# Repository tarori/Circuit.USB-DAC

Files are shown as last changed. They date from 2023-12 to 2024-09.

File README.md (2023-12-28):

USB Audio DAC version 10
 * Input: USB Audio class 2.0 (192kHz/24bit)
 * Output: Headphone and speakers (max 5W @8Ω)
 * THD+N < -100dB (0.001%) at 1W 8Ω 
 * Low output noise: <10uVrms (20-20kHz)
 * 4-layer PCB with solid ground
 * SDR-Widget with very low jitter design
 * Isolated USB input
 * AK4493 with AK1110 and [LED regulators](https://github.com/tarori/Circuit.LEC-Regulator) (discrete low noise, low impedance regulator) 
 * Low gain class-AB amplifier
 * Two mute relays for headphone and speakers
 * Input power: ±20V 2A

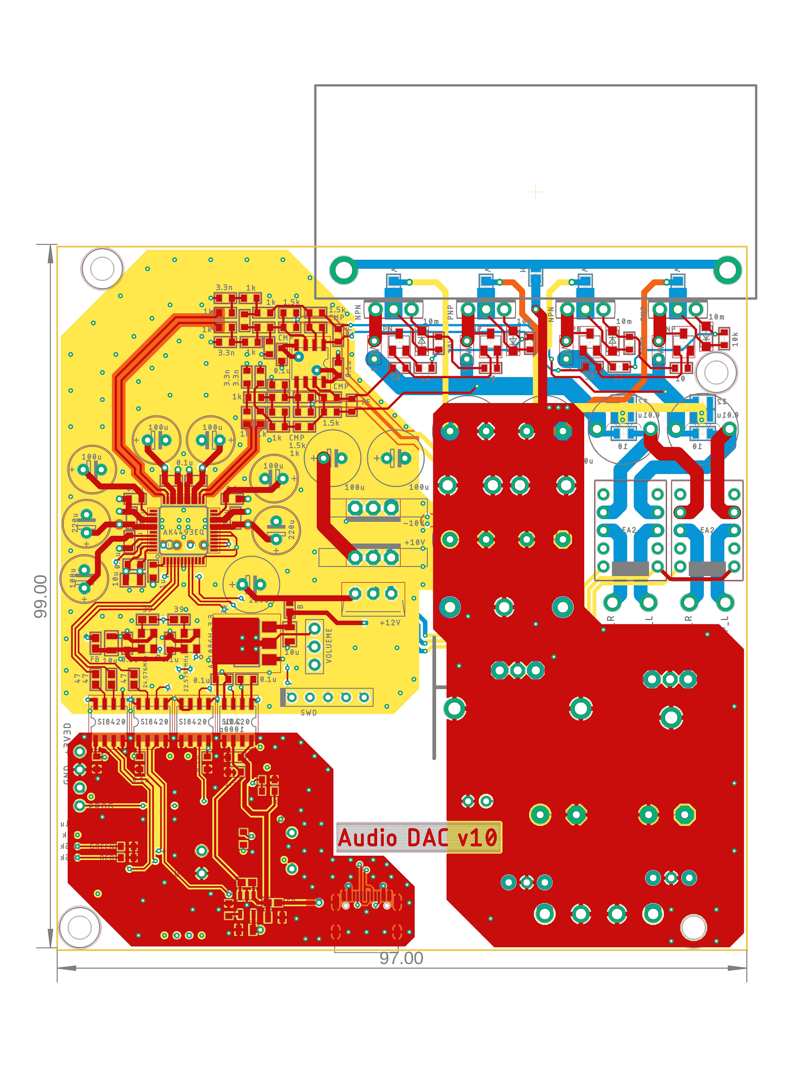
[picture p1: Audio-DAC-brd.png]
ボード図

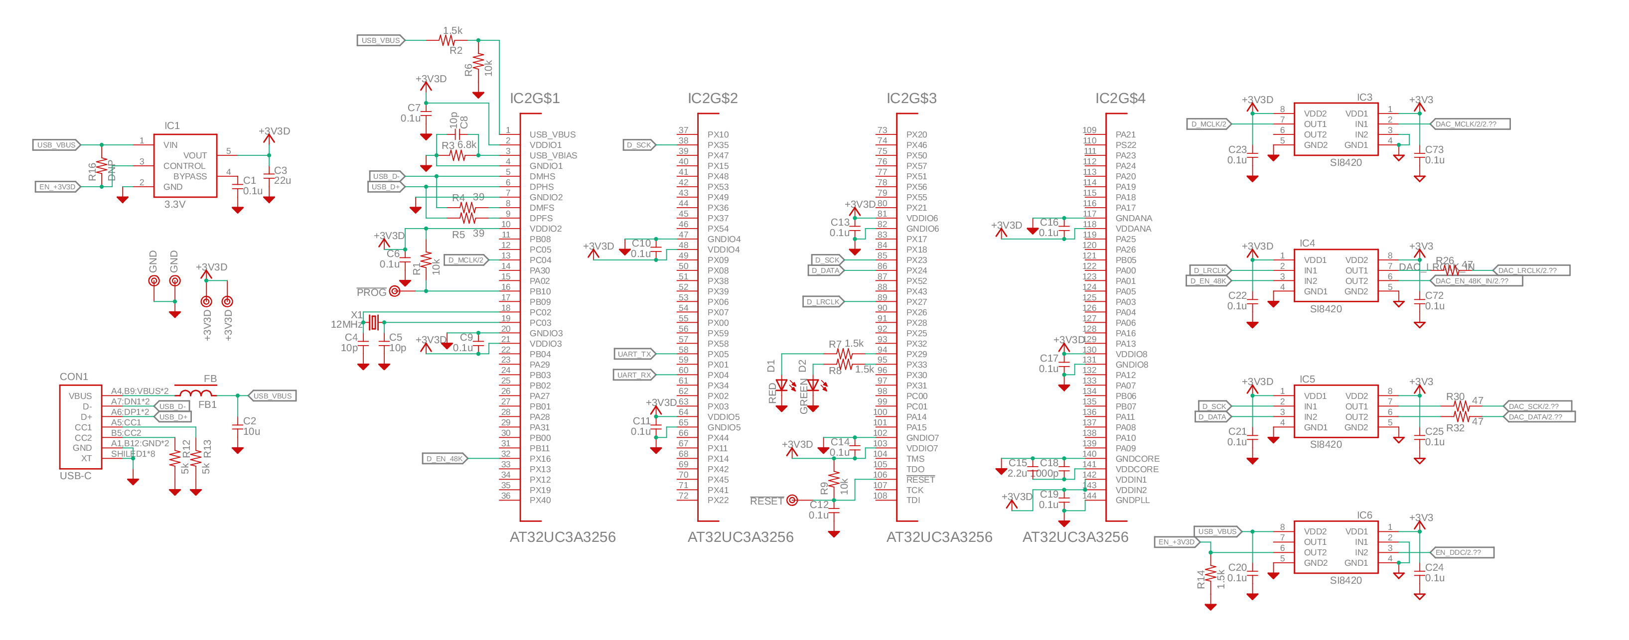
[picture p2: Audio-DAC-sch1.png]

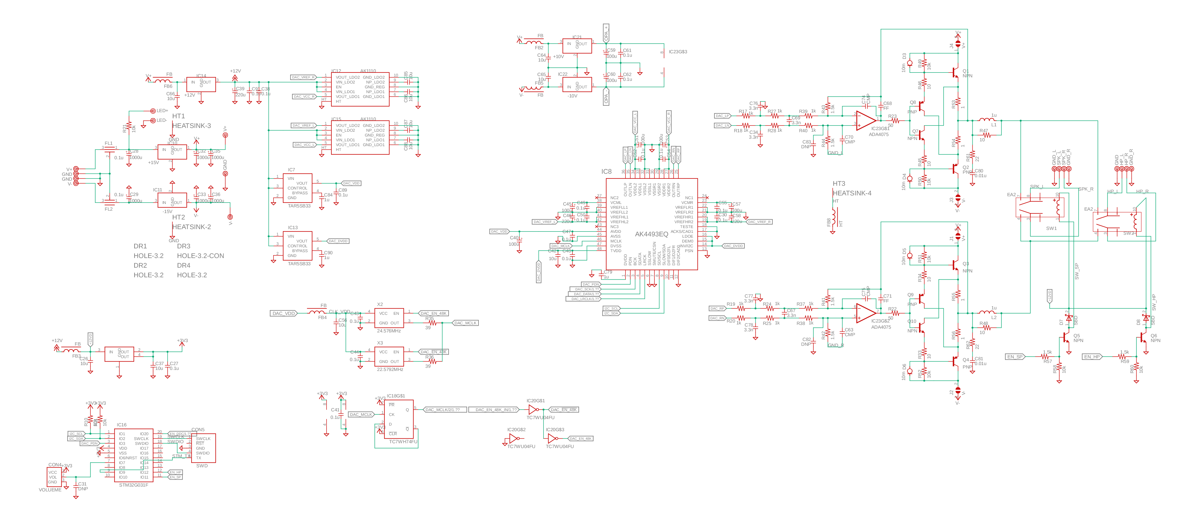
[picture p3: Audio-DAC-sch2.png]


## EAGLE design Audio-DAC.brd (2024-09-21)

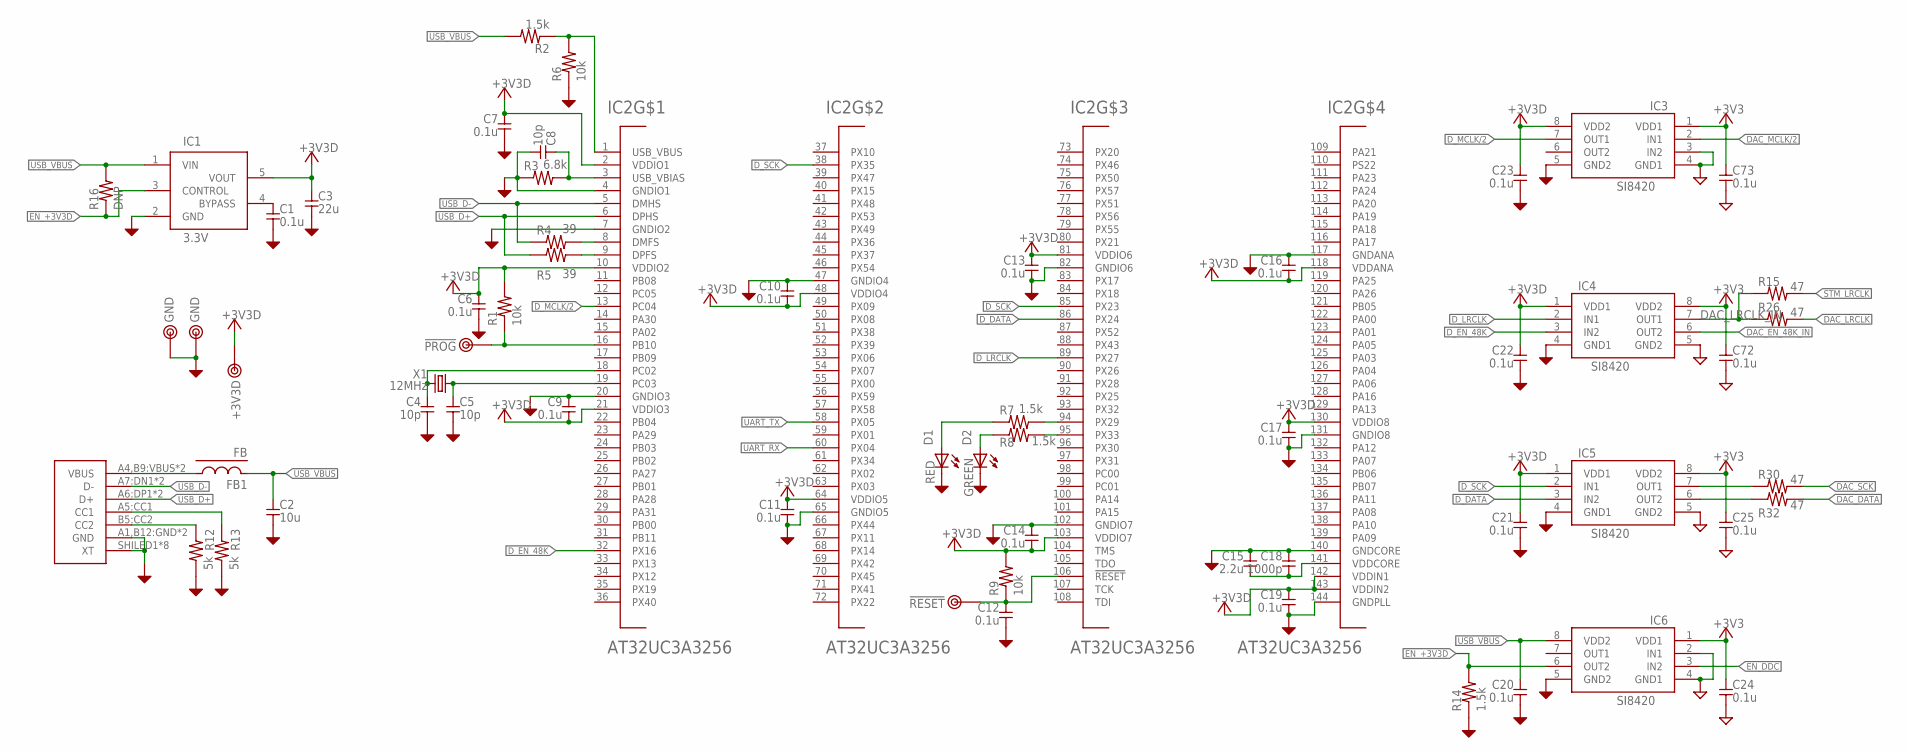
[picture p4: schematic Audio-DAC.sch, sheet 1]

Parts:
C1, C6, C7, C9, C10, C11, C12, C13, C14, C16, C17, C19, C20, C21, C22, C23, C24, C25, C72, C73: 0.1u; 1608C
C2: 10u; 2012
C3: 22u; 2012
C4, C5, C8: 10p; 1608C
C15: 2.2u; 2012
C18: 1000p; 1608C
CON1: USB-C; 5077CR-16-SMC2-BK-TR
D1: RED; D1608
D2: GREEN; D1608
FB1: FB; 1608-J
IC1: 3.3V; SOT23-5
IC2: AT32UC3A3256; TQFP144
IC3, IC4, IC5, IC6: SI8420; SOP8
R1, R6, R9: 10k; 1608
R2, R7, R8, R14: 1.5k; 1608
R3: 6.8k; 1608
R4, R5: 39; 1608
R12, R13: 5k; 1608
R15, R26, R30, R32: 47; 1608-J
R16: DNP; 1608-J
TP1: !PROG; TESTPIN
TP2: !RESET; TESTPIN
TP3, TP25: GND; TESTPIN
TP26: +3V3D; TESTPIN
X1: 12MHz; HC49/S

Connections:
+3V3: C24.1, C25.1, C72.1, C73.1, IC3.1 (VDD1), IC4.8 (VDD2), IC5.8 (VDD2), IC6.1 (VDD1); also elsewhere on the board
+3V3D: C3.1, C6.1, C7.1, C9.2, C10.2, C11.1, C13.1, C14.2, C16.2, C17.1, C19.1, C21.1, C22.1, C23.1, IC1.5 (VOUT), IC2.2 (VDDIO1), IC2.10 (VDDIO2), IC2.21 (VDDIO3), IC2.48 (VDDIO4), IC2.64 (VDDIO5), IC2.81 (VDDIO6), IC2.103 (VDDIO7), IC2.118 (VDDANA), IC2.130 (VDDIO8), IC2.142 (VDDIN1), IC2.143 (VDDIN2), IC3.8 (VDD2), IC4.1 (VDD1), IC5.1 (VDD1), R1.2, R9.2, TP26.1
AVR_PROG: IC2.16 (PB10), R1.1, TP1.1
DAC_DATA: R32.2; also elsewhere on the board
DAC_EN_48K_IN: IC4.6 (OUT2); also elsewhere on the board
DAC_LRCLK: R26.2; also elsewhere on the board
DAC_LRCLK_IN: IC4.7 (OUT1), R15.1, R26.1
DAC_MCLK/2: IC3.2 (IN1); also elsewhere on the board
DAC_SCK: R30.2; also elsewhere on the board
DGND: C1.2, C2.2, C3.2, C4.2, C5.2, C6.2, C7.2, C8.2, C9.1, C10.1, C11.2, C12.2, C13.2, C14.1, C15.1, C16.1, C17.2, C18.1, C19.2, C20.2, C21.2, C22.2, C23.2, CON1.A1,B12:GND (GND), CON1.B1,A12:GND (GND), CON1.SHILED1 (XT), CON1.SHILED2 (XT), CON1.SHILED3 (XT), CON1.SHILED4 (XT), CON1.SHILED5 (XT), CON1.SHILED6 (XT), CON1.SHILED7 (XT), CON1.SHILED8 (XT), D1.K, D2.K, IC1.2 (GND), IC2.4 (GNDIO1), IC2.7 (GNDIO2), IC2.20 (GNDIO3), IC2.47 (GNDIO4), IC2.65 (GNDIO5), IC2.82 (GNDIO6), IC2.102 (GNDIO7), IC2.117 (GNDANA), IC2.131 (GNDIO8), IC2.140 (GNDCORE), IC2.144 (GNDPLL), IC3.5 (GND2), IC4.4 (GND1), IC5.4 (GND1), IC6.5 (GND2), R3.1, R6.1, R12.1, R13.1, R14.1, TP3.1, TP25.1
D_!RST: C12.1, IC2.106 (!RESET), R9.1, TP2.1
D_DATA: IC2.86 (PX24), IC5.3 (IN2)
D_EN_48K: IC2.32 (PX16), IC4.3 (IN2)
D_LRCLK: IC2.89 (PX27), IC4.2 (IN1)
D_MCLK/2: IC2.13 (PC04), IC3.7 (OUT1)
D_SCK: IC2.38 (PX35), IC2.85 (PX23), IC5.2 (IN1)
EN_+3V3D: IC1.3 (CONTROL), IC6.6 (OUT2), R14.2, R16.1
EN_DDC: IC6.3 (IN2); also elsewhere on the board
GND: C24.2, C25.2, C72.2, C73.2, IC3.3 (IN2), IC3.4 (GND1), IC4.5 (GND2), IC5.5 (GND2), IC6.2 (IN1), IC6.4 (GND1); also elsewhere on the board
LED_GREEN: IC2.95 (PX33), R8.2
LED_RED: IC2.94 (PX29), R7.2
unnamed: IC2.8 (DMFS), R4.2
unnamed: IC2.9 (DPFS), R5.2
unnamed: C5.1, IC2.19 (PC03), X1.1
unnamed: C4.1, IC2.18 (PC02), X1.2
unnamed: C8.1, IC2.3 (USB_VBIAS), R3.2
unnamed: IC2.1 (USB_VBUS), R2.1, R6.2
unnamed: D2.A, R8.1
unnamed: C15.2, C18.2, IC2.141 (VDDCORE)
unnamed: D1.A, R7.1
unnamed: IC5.7 (OUT1), R30.1
unnamed: C1.1, IC1.4 (BYPASS)
unnamed: CON1.B5:CC2 (CC2), R12.2
unnamed: CON1.A5:CC1 (CC1), R13.2
unnamed: IC5.6 (OUT2), R32.1
STM_LRCLK: R15.2; also elsewhere on the board
UART_RX: IC2.60 (PX04)
UART_TX: IC2.58 (PX05)
USB_D+: CON1.A6:DP1 (D+), CON1.B6:DP2 (D+), IC2.6 (DPHS), R5.1
USB_D-: CON1.A7:DN1 (D-), CON1.B7:DN2 (D-), IC2.5 (DMHS), R4.1
USB_VBUS: C2.1, C20.1, FB1.2, IC1.1 (VIN), IC6.8 (VDD2), R2.2, R16.2
VBUS: CON1.A4,B9:VBUS (VBUS), CON1.B4,A9:VBUS (VBUS), FB1.1

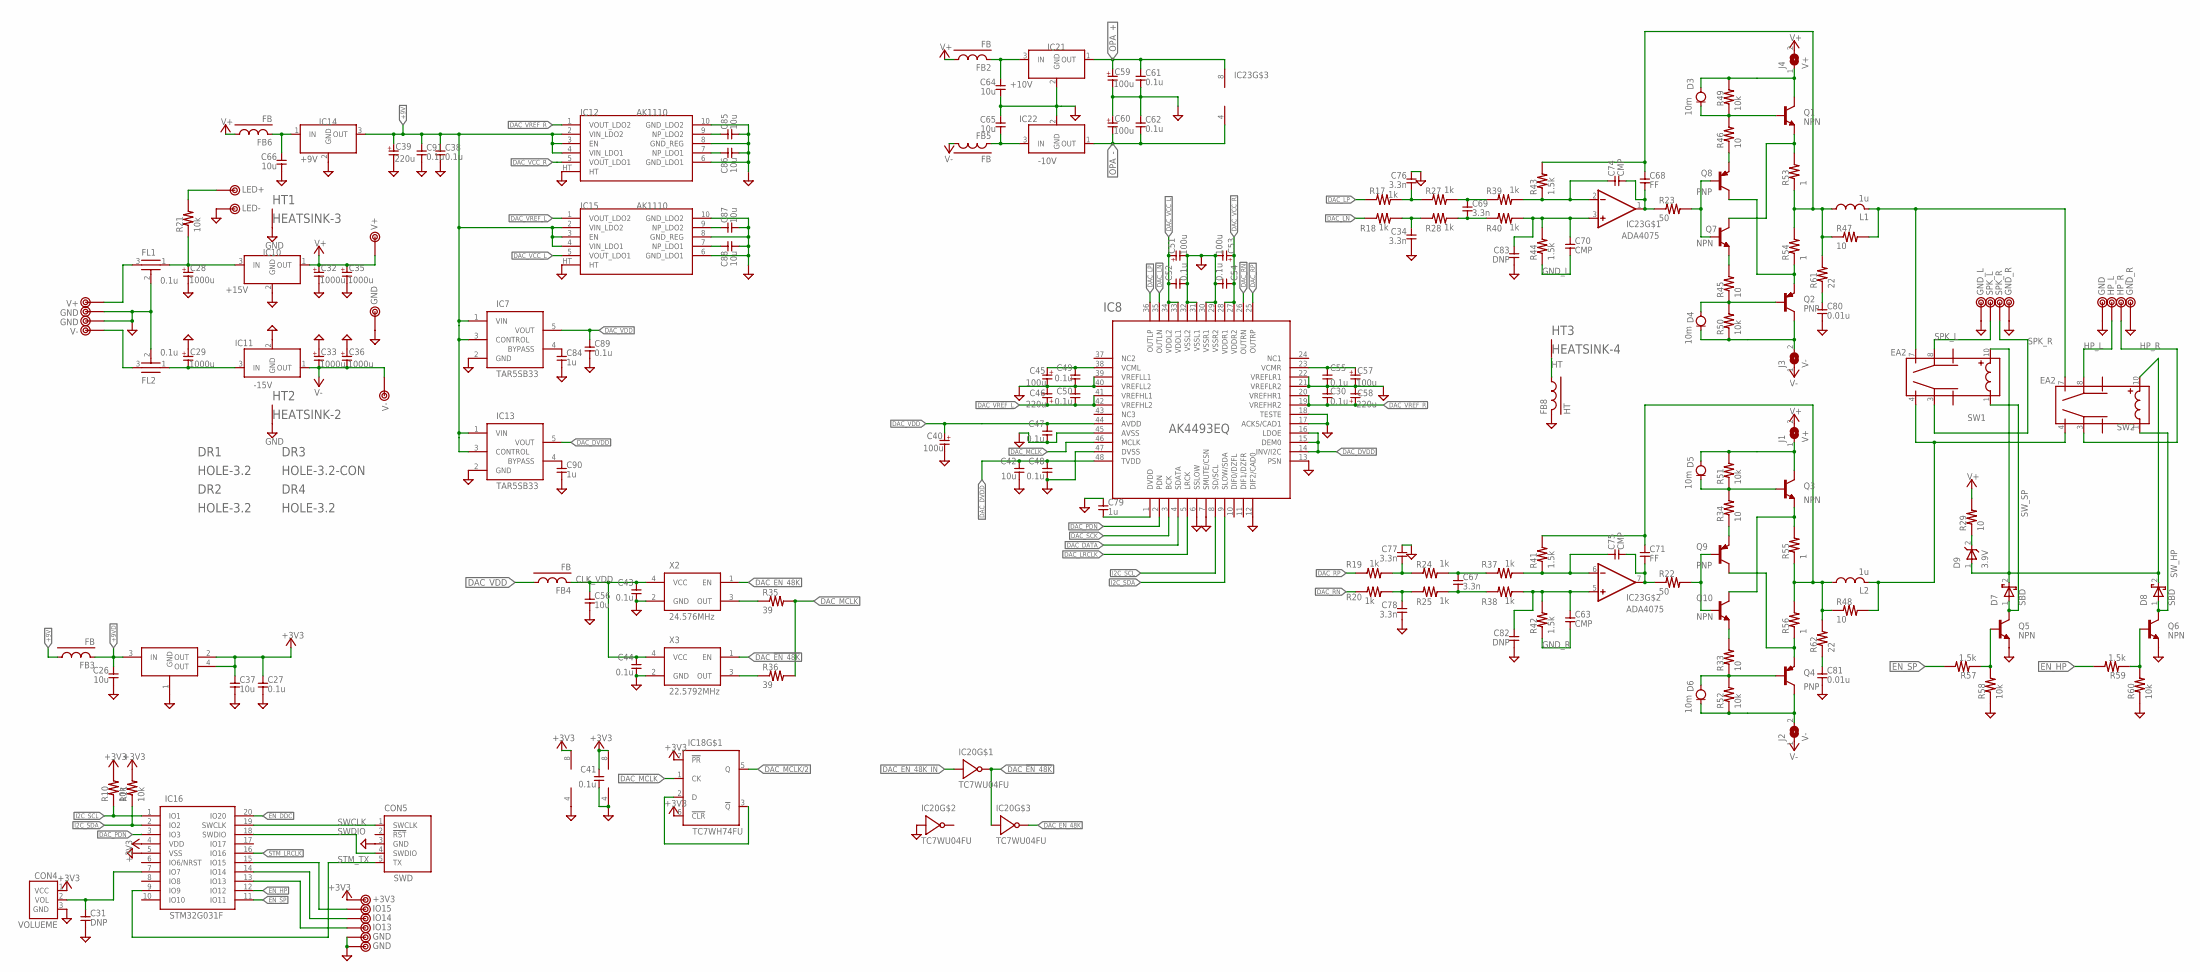
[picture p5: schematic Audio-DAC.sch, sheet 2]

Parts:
C26, C37, C42, C56, C64, C65, C66, C85, C86, C87, C88: 10u; 2012
C27, C30, C38, C41, C43, C44, C47, C48, C49, C50, C52, C54, C55, C61, C62, C89, C91: 0.1u; 1608C
C28, C29: 1000u; E5-13
C31, C82, C83: DNP; 1608C
C32, C33, C35, C36: 1000u; E5-10
C34, C67, C69, C76, C77, C78: 3.3n; 1608C
C39: 220u; E2,5-8
C40, C45, C51, C53, C57: 100u; E2.5-6.5
C46, C58: 220u; E2.5-6.5
C59, C60: 100u; E2,5-8
C63, C70, C74, C75: CMP; 1608C
C68, C71: FF; 1608C
C79, C84, C90: 1u; 1608C
C80, C81: 0.01u; 2012
CON4: VOLUEME; VOL_CON
CON5: SWD; SWD_CON
D3, D4, D5, D6: 10m; SOD123
D7, D8: SBD; SOD123
D9: 3.9V; SOD123
DR1, DR2, DR4: HOLE-3.2; HOLE_3.2
DR3: HOLE-3.2-CON; HOLE_3.2_CON
FB2, FB3, FB4, FB5, FB6: FB; 1608-J
FB8: HT; 2012-J
FL1, FL2: 0.1u; FL1
HT1: HEATSINK-3; HEATSINK3
HT2: HEATSINK-2; HEATSINK2
HT3: HEATSINK-4; HEATSINK4
IC7, IC13: TAR5SB33; SOT23-5
IC8: AK4493EQ; LQFP48
IC9: AZ1086H-3.3; SOT223
IC10: +15V; REGULATOR_LED
IC11: -15V; REGULATOR_LED
IC12, IC15: AK1110; PLP10-SMD
IC14: +9V; TO-220
IC16: STM32G031F; TSSOP20
IC18: TC7WH74FU; SSOP8-P-0.65
IC20: TC7WU04FU; SSOP8-P-0.65
IC21: +10V; REGULATOR_LED
IC22: -10V; REGULATOR_LED
IC23: ADA4075; SOP8
J1, J4: V+; 2012-J
J2, J3: V-; 2012-J
L1, L2: 1u; L7-10-2
Q1, Q3: NPN; TO126
Q2, Q4: PNP; TO126
Q5, Q6, Q7, Q10: NPN; SC59
Q8, Q9: PNP; SC59
R10, R11, R49, R50, R51, R52, R58, R60: 10k; 1608
R17, R18, R19, R20, R24, R25, R27, R28, R37, R38, R39, R40: 1k; 1608
R21: 10k; 2012
R22, R23: 50; 1608
R29, R47, R48: 10; 2012
R33, R34, R45, R46: 10; 1608
R35, R36: 39; 1608-J
R41, R42, R43, R44, R57, R59: 1.5k; 1608
R53, R55, R56: 1; 0207/2V
R54: 1; 0204/5
R61, R62: 22; 2012
SW1, SW2: EA2
TP5, TP11: V+; TESTPIN-BIG
TP6, TP7, TP22, TP31: GND; TESTPIN-BIG
TP8, TP21: V-; TESTPIN-BIG
TP9: IO15; TESTPIN
TP10: IO14; TESTPIN
TP12: IO13; TESTPIN
TP13, TP14: GND; TESTPIN
TP15: LED+; TESTPIN
TP16: LED-; TESTPIN
TP17: +3V3; TESTPIN
TP27: GND_L; TESTPIN-BIG
TP28: SPK_L; TESTPIN-BIG
TP29: SPK_R; TESTPIN-BIG
TP30, TP34: GND_R; TESTPIN-BIG
TP32: HP_L; TESTPIN-BIG
TP33: HP_R; TESTPIN-BIG
X2: 24.576MHz; KC3225
X3: 22.5792MHz; KC3225

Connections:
+3V3: C27.1, C37.1, C41.1, CON4.1 (VCC), IC9.2 (OUT), IC9.4 (OUT), IC16.4 (VDD), IC18.6 (!CLR), IC18.7 (!PR), IC18.8 (V+), IC20.8 (V+), R10.2, R11.2, TP17.1; also elsewhere on the board
+9V: C38.1, C39.+ (1), C91.1, FB3.1, IC7.1 (VIN), IC7.3 (CONTROL), IC12.2 (VIN_LDO2), IC12.3 (EN), IC12.4 (VIN_LDO1), IC13.1 (VIN), IC13.3 (CONTROL), IC14.3 (OUT), IC15.2 (VIN_LDO2), IC15.3 (EN), IC15.4 (VIN_LDO1)
+9VD: C26.1, FB3.2, IC9.3 (IN)
+12V: D7.2 (K), D8.2 (K), D9.1 (A), SW1.10 (L2), SW2.10 (L2)
AMP_LOUT: C68.1, L1.1, R43.2, R47.1, R53.1, R54.2, R61.2
AMP_ROUT: C71.1, L2.1, R41.2, R48.1, R55.1, R56.2, R62.2
CLK_VDD: C43.1, C44.1, C56.1, FB4.2, X2.4 (VCC), X3.4 (VCC)
DAC_!EN_48K: IC20.3 (IN), IC20.7 (OUT), X3.1 (EN)
DAC_DATA: IC8.4 (SDATA); also elsewhere on the board
DAC_DVDD: C42.1, C48.1, IC8.14 (INV/I2C), IC8.15 (DEM0), IC8.16 (LDOE), IC8.48 (TVDD), IC13.5 (VOUT)
DAC_EN_48K: IC20.5 (OUT), X2.1 (EN)
DAC_EN_48K_IN: IC20.1 (IN); also elsewhere on the board
DAC_LN: IC8.35 (OUTLN), R18.1
DAC_LP: IC8.36 (OUTLP), R17.1
DAC_LRCLK: IC8.5 (LRCK); also elsewhere on the board
DAC_MCLK: IC8.46 (MCLK), IC18.1 (CK), R35.2, R36.2
DAC_MCLK/2: IC18.5 (Q); also elsewhere on the board
DAC_PDN: IC8.2 (PDN), IC16.3 (IO3)
DAC_RN: IC8.26 (OUTRN), R20.1
DAC_RP: IC8.25 (OUTRP), R19.1
DAC_SCK: IC8.3 (BCK); also elsewhere on the board
DAC_VCC_L: C51.+ (1), C52.1, IC8.33 (VDDL1), IC8.34 (VDDL2), IC15.5 (VOUT_LDO1)
DAC_VCC_R: C53.+ (1), C54.1, IC8.27 (VDDR2), IC8.28 (VDDR1), IC12.5 (VOUT_LDO1)
DAC_VDD: C40.+ (1), C47.1, C89.1, FB4.1, IC7.5 (VOUT), IC8.44 (AVDD)
DAC_VREF_L: C46.+ (1), C50.2, IC8.41 (VREFHL1), IC8.42 (VREFHL2), IC15.1 (VOUT_LDO2)
DAC_VREF_R: C30.2, C58.+ (1), IC8.19 (VREFHR2), IC8.20 (VREFHR1), IC12.1 (VOUT_LDO2)
EN_DDC: IC16.20 (IO20); also elsewhere on the board
EN_HP: IC16.12 (IO12), R59.2
EN_SP: IC16.11 (IO11), R57.2
GND: C26.2, C27.2, C28.- (2), C29.+ (1), C30.1, C31.2, C32.- (2), C33.+ (1), C34.2, C35.- (2), C36.+ (1), C37.2, C38.2, C39.- (2), C40.- (2), C41.2, C42.2, C43.2, C44.2, C45.- (2), C46.- (2), C47.2, C48.2, C49.2, C50.1, C51.- (2), C52.2, C53.- (2), C54.2, C55.2, C56.2, C57.- (2), C58.- (2), C59.- (2), C60.+ (1), C61.2, C62.1, C64.2, C65.1, C66.2, C76.1, C77.1, C78.2, C79.1, C80.2, C81.2, C82.2, C83.2, C84.2, C85.2, C86.2, C87.2, C88.2, C89.2, C90.2, C91.2, CON4.3 (GND), CON5.3 (GND), FB8.2, FL1.2 (GND), FL2.2 (GND), HT1.HT1, HT1.HT2, HT2.HT1, IC7.2 (GND), IC8.6 (SSLOW), IC8.7 (SMUTE/CSN), IC8.12 (DIF2/CAD0), IC8.13 (PSN), IC8.17 (ACKS/CAD1), IC8.18 (TESTE), IC8.21 (VREFLR2), IC8.22 (VREFLR1), IC8.29 (VSSR2), IC8.30 (VSSR1), IC8.31 (VSSL1), IC8.32 (VSSL2), IC8.39 (VREFLL1), IC8.40 (VREFLL2), IC8.45 (AVSS), IC8.47 (DVSS), IC9.1 (GND), IC10.2 (GND), IC11.2 (GND), IC12.6 (GND_LDO1), IC12.8 (GND_REG), IC12.10 (GND_LDO2), IC12.HT, IC13.2 (GND), IC14.2 (GND), IC15.6 (GND_LDO1), IC15.8 (GND_REG), IC15.10 (GND_LDO2), IC15.HT, IC16.5 (VSS), IC18.4 (V-), IC20.4 (V-), IC20.6 (IN), IC21.2 (GND), IC22.2 (GND), Q5.2 (E), Q6.2 (E), R58.1, R60.1, TP6.1, TP7.1, TP13.1, TP14.1, TP16.1, TP22.1, TP27.1, TP30.1, TP31.1, TP34.1, X2.2 (GND), X3.2 (GND); also elsewhere on the board
GND_L: C70.2, R44.1
GND_R: C63.2, R42.1
HP_L: SW2.8 (COM2), TP32.1
HP_R: SW2.3 (COM1), TP33.1
HT: FB8.1, HT3.HT1, HT3.HT2
I2C_SCL: IC8.8 (SD/SCL), IC16.1 (IO1), R10.1
I2C_SDA: IC8.9 (SLOW/SDA), IC16.2 (IO2), R11.1
unnamed: C84.1, IC7.4 (BYPASS)
unnamed: C86.1, IC12.7 (NP_LDO1)
unnamed: C85.1, IC12.9 (NP_LDO2)
unnamed: C87.1, IC15.9 (NP_LDO2)
unnamed: D4.1 (A), Q2.3 (B), R45.1, R50.2
unnamed: C90.1, IC13.4 (BYPASS)
unnamed: C64.1, FB2.2, IC21.3 (IN)
unnamed: C75.1, IC23.6 (-IN), R37.2, R41.1
unnamed: C63.1, C82.1, IC23.5 (+IN), R38.2, R42.2
unnamed: C65.2, FB5.2, IC22.3 (IN)
unnamed: C66.1, FB6.2, IC14.1 (IN)
unnamed: Q3.1 (E), Q10.3 (C), R55.2
unnamed: Q9.1 (B), Q10.1 (B), R22.2
unnamed: C69.1, R27.2, R39.1
unnamed: Q4.1 (E), Q9.3 (C), R56.1
unnamed: Q9.2 (E), R34.1
unnamed: Q2.1 (E), Q8.3 (C), R54.1
unnamed: Q1.1 (E), Q7.3 (C), R53.2
unnamed: L2.2, R48.2, SW1.4 (A1), SW2.4 (A1)
unnamed: L1.2, R47.2, SW1.7 (A2), SW2.7 (A2)
unnamed: Q5.1 (B), R57.1, R58.2
unnamed: IC16.13 (IO13), TP12.1
unnamed: C69.2, R28.2, R40.1
unnamed: IC16.14 (IO14), TP10.1
unnamed: FL1.3 (IN), TP5.1
unnamed: FL2.3 (IN), TP8.1
unnamed: C77.2, R19.2, R24.1
unnamed: C78.1, R20.2, R25.1
unnamed: R21.2, TP15.1
unnamed: C74.1, IC23.2 (-IN), R39.2, R43.1
unnamed: C70.1, C83.1, IC23.3 (+IN), R40.2, R44.2
unnamed: C79.2, IC8.1 (DVDD)
unnamed: C71.2, C75.2, IC23.7 (OUT), R22.1
unnamed: Q6.1 (B), R59.1, R60.2
unnamed: D3.2 (K), Q1.3 (B), R46.2, R49.1
unnamed: C68.2, C74.2, IC23.1 (OUT), R23.1
unnamed: Q10.2 (E), R33.2
unnamed: IC16.15 (IO15), TP9.1
unnamed: Q7.1 (B), Q8.1 (B), R23.2
unnamed: D6.1 (A), Q4.3 (B), R33.1, R52.2
unnamed: D6.2 (K), J2.2, Q4.2 (C), R52.1
unnamed: D5.2 (K), Q3.3 (B), R34.2, R51.1
unnamed: Q7.2 (E), R45.2
unnamed: Q8.2 (E), R46.1
unnamed: C67.1, R24.2, R37.1
unnamed: D5.1 (A), J1.1, Q3.2 (C), R51.2
unnamed: D4.2 (K), J3.2, Q2.2 (C), R50.1
unnamed: D3.1 (A), J4.1, Q1.2 (C), R49.2
unnamed: C67.2, R25.2, R38.1
unnamed: C76.2, R17.2, R27.1
unnamed: C34.1, R18.2, R28.1
unnamed: C80.1, R61.1
unnamed: C81.1, R62.1
unnamed: C88.1, IC15.7 (NP_LDO1)
unnamed: D9.2 (C), R29.1
unnamed: C31.1, CON4.2 (VOL), IC16.7 (IO7)
unnamed: R35.1, X2.3 (OUT)
unnamed: R36.1, X3.3 (OUT)
unnamed: IC18.2 (D), IC18.3 (!Q)
OPA_+: C59.+ (1), C61.1, IC21.1 (OUT), IC23.8 (V+)
OPA_-: C60.- (2), C62.2, IC22.1 (OUT), IC23.4 (V-)
SPK_L: SW1.8 (COM2), TP28.1
SPK_R: SW1.3 (COM1), TP29.1
STM_LRCLK: IC16.16 (IO16); also elsewhere on the board
STM_TX: CON5.5 (TX), IC16.9 (IO9)
SWCLK: CON5.1 (SWCLK), IC16.19 (SWCLK)
SWDIO: CON5.4 (SWDIO), IC16.18 (SWDIO)
SW_HP: D8.1 (A), Q6.3 (C), SW2.1 (L1)
SW_SP: D7.1 (A), Q5.3 (C), SW1.1 (L1)
V+: C32.+ (1), C35.+ (1), FB2.1, FB6.1, IC10.1 (OUT), J1.2, J4.2, R29.2, TP11.1
V-: C33.- (2), C36.- (2), FB5.1, IC11.1 (OUT), J2.1, J3.1, TP21.1
VCOM_L: C45.+ (1), C49.1, IC8.38 (VCML)
VCOM_R: C55.1, C57.+ (1), IC8.23 (VCMR)
VIN+: C28.+ (1), FL1.1 (OUT), IC10.3 (IN), R21.1
VIN-: C29.- (2), FL2.1 (OUT), IC11.3 (IN)

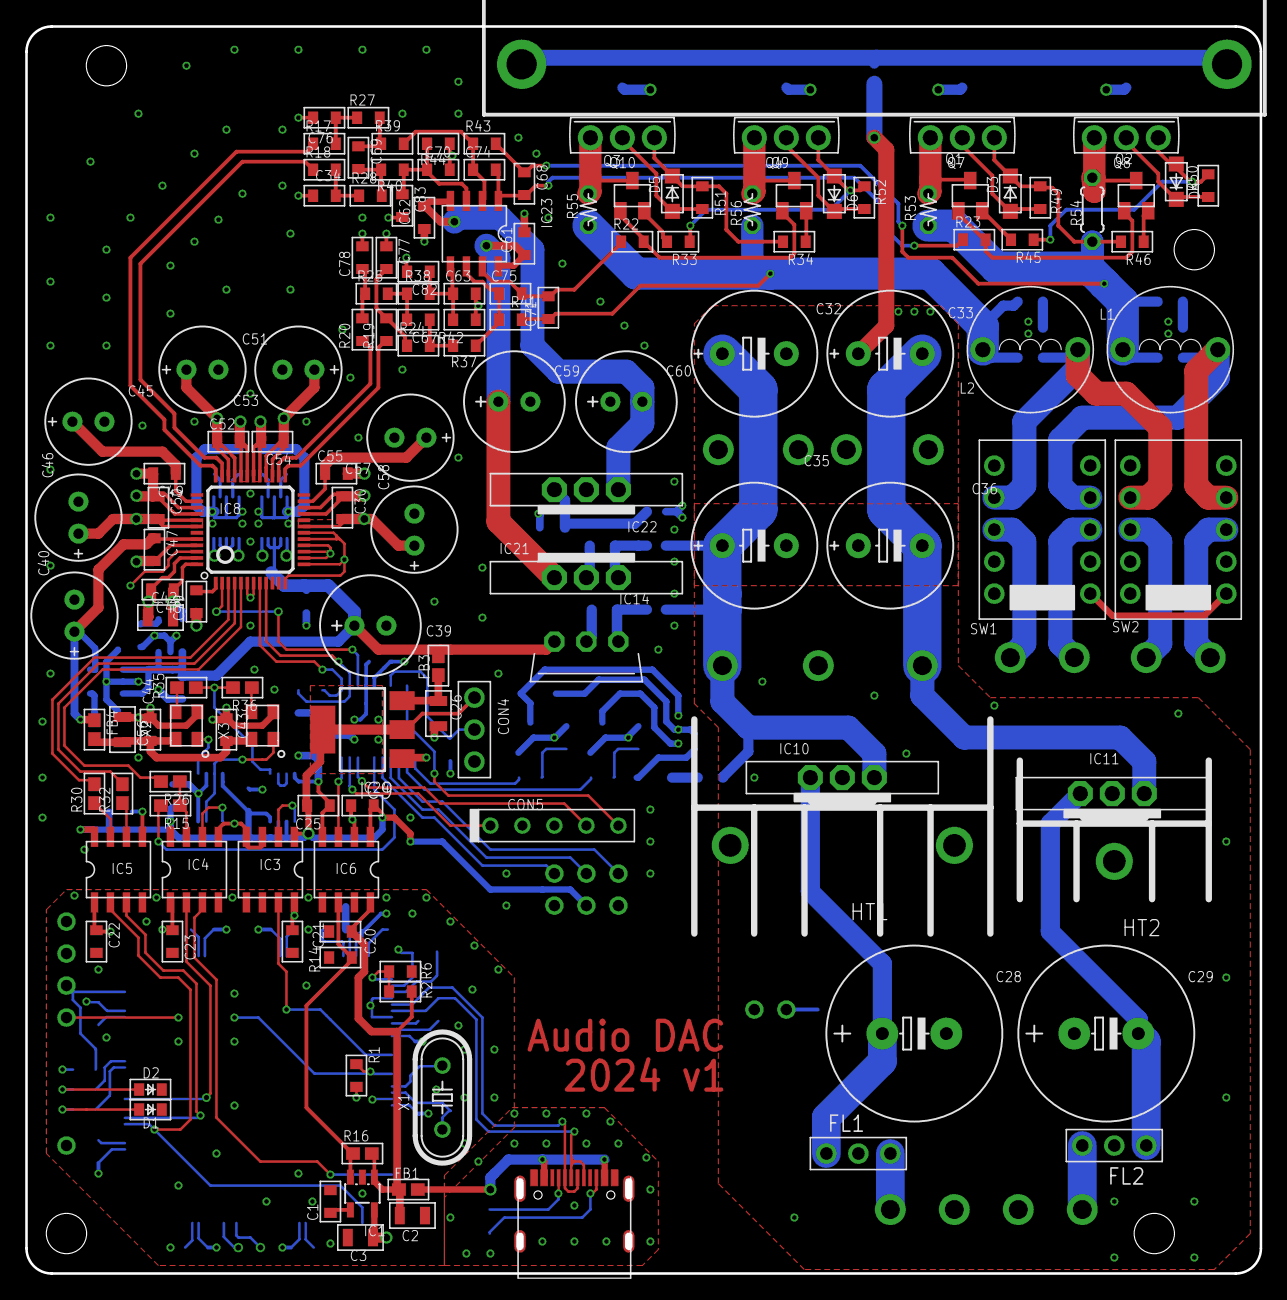
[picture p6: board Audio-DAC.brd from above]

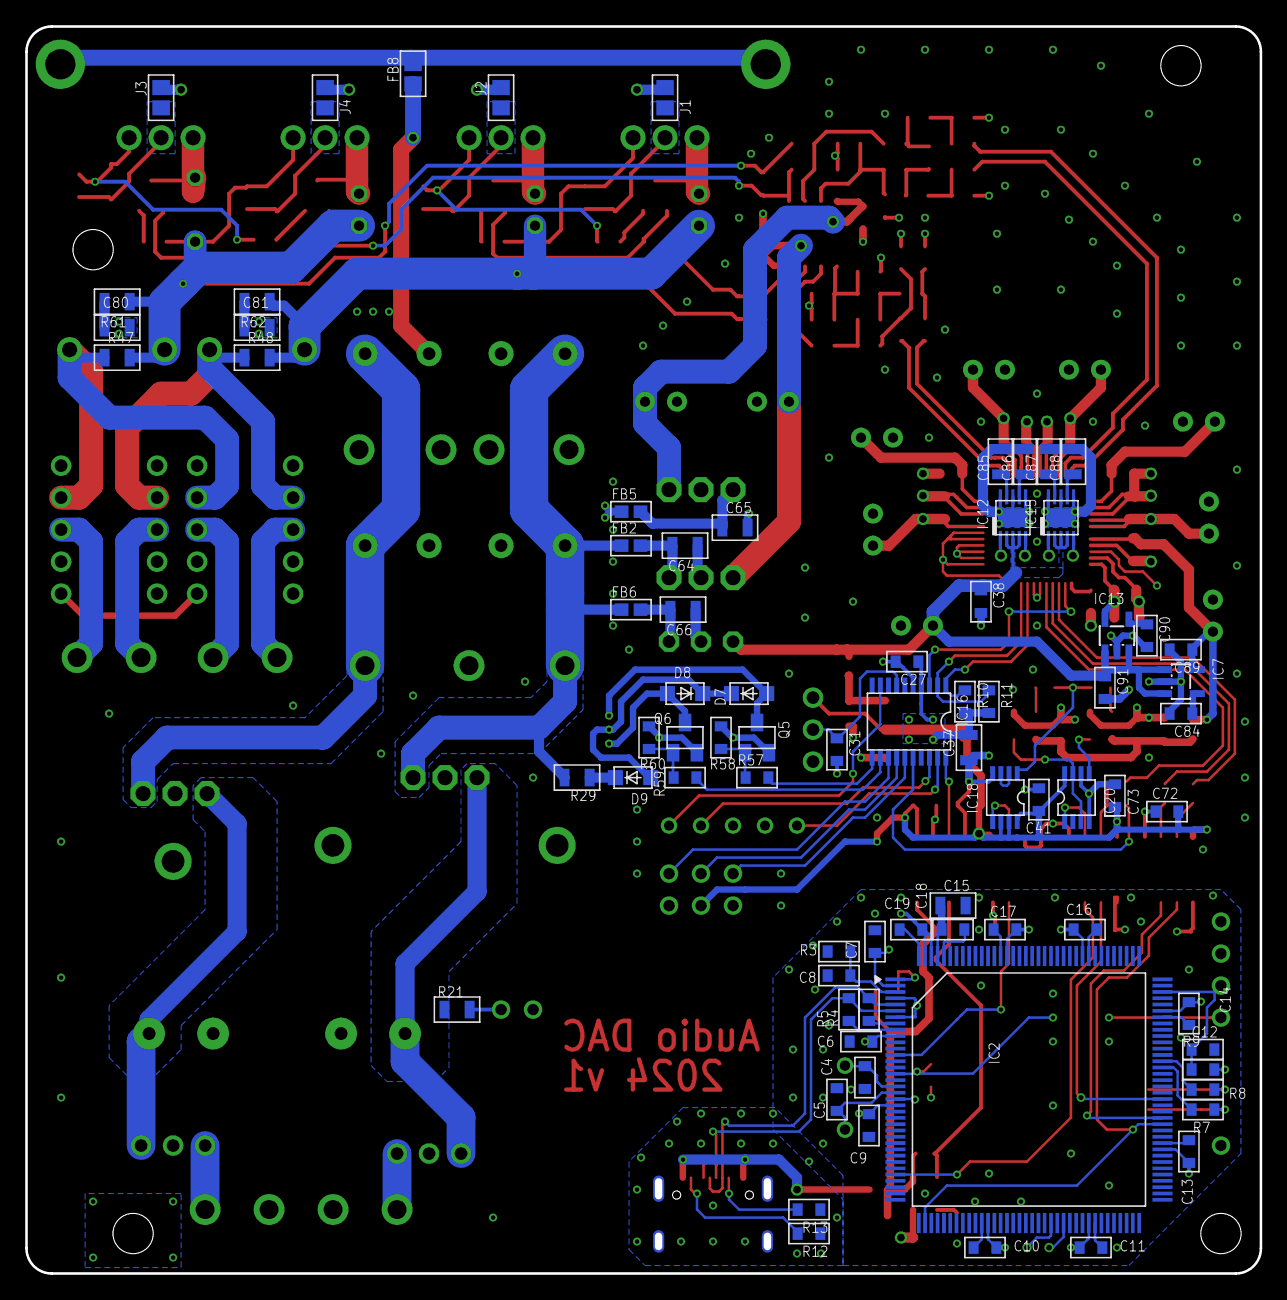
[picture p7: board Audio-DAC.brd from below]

Board: 4 copper layers, 98.0 x 99.0 mm, 250 parts (77 on the bottom side), 143 nets.

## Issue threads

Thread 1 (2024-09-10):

Component values

jahquubel, 2024-09-10:
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
Hello thanks for sharing this schematic.

What are the  of the component values around  ADA4075 or what  DNP, CMP or FF means here?

tarori, 2024-09-10:
They are tuning knobs for high frequency characteristics.
I don't populate components for these DNP/CMP/FF, with ADA4075 or OPA1656. But if you use a very high-performance opamp, like LME49990, you may need to put 10pF-100pF capacitor at CMP or FF, to prevent oscillation.

jahquubel, 2024-09-10:
Got it thanks !

I am trying to modify it with ADA4075 as the output without amplification.
I will leave r43 and just check designs, maybe just short ff and take output from R23.

Closed 2024-09-10.

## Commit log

2020-07-10 デジタル部の回路図
    [Audio-DAC.sch]
2020-07-11 アイソレーター追加
    [Audio-DAC.sch]
2020-07-12 デジタル部配置
    [Audio-DAC.brd, Audio-DAC.sch]
2020-07-13 べた以外できた
    [Audio-DAC.brd, Audio-DAC.sch]
2020-07-13 DDCのフォトカプラ追加
    [Audio-DAC.brd, Audio-DAC.sch]
2020-07-14 ほぼ完成
    [Audio-DAC.brd]
2020-07-15 ビアを打った
    [Audio-DAC.brd]
2020-07-15 フォトカプラを反転
    [Audio-DAC.brd, Audio-DAC.sch]
2020-07-15 アイソレーターをsi8420に
    [Audio-DAC.brd, Audio-DAC.sch]
2020-07-16 fix readme
    [Audio-DAC.brd]
2020-08-12 Change to AK4493
    [Audio-DAC.brd, Audio-DAC.sch]
2020-08-13 大体できた
    [Audio-DAC.brd, Audio-DAC.sch]
2020-08-13 シルク調整
    [Audio-DAC.brd]
2021-03-09 PCM1795途中
    [Audio-DAC.brd, Audio-DAC.sch]
2021-03-16 だいたい
    [Audio-DAC.brd, Audio-DAC.sch]
2021-03-16 全部つないだ
    [Audio-DAC.brd, Audio-DAC.sch]
2021-03-16 バージョン
    [Audio-DAC.brd]
2021-03-16 シルク整えた
    [Audio-DAC.brd, Audio-DAC.sch]
2021-03-16 Add 位相補償
    [Audio-DAC.brd, Audio-DAC.sch]
2021-04-17 fix PCM1795
    [Audio-DAC.brd, Audio-DAC.sch]
2021-08-25 AK4495に変える
    [Audio-DAC.brd, Audio-DAC.sch]
2022-03-17 ヒートシンクつけた
    [Audio-DAC.brd, Audio-DAC.sch]
2022-03-18 LPF追加
    [Audio-DAC.brd, Audio-DAC.sch]
2022-03-20 AK4493に
    [Audio-DAC.brd, Audio-DAC.sch]
2022-12-17 LPF強化&発振対策
    [Audio-DAC.brd, Audio-DAC.sch]
2023-08-18 AK1110に変更中
    [Audio-DAC.brd, Audio-DAC.sch]
2024-09-21 バッファ改良
    [Audio-DAC.brd, Audio-DAC.sch]
